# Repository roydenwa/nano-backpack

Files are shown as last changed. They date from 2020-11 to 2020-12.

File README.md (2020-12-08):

# Nano-backpack for NAO robot
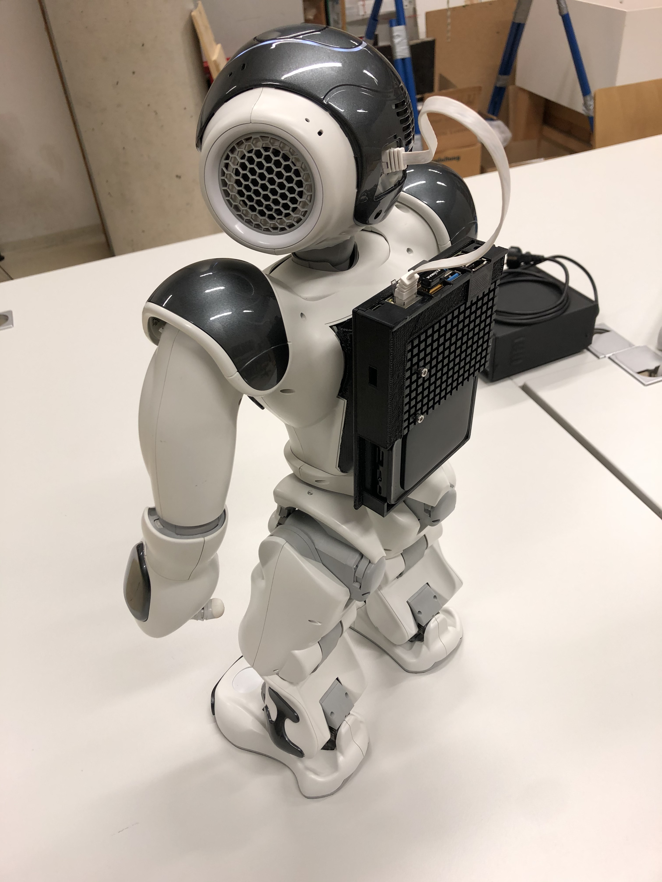
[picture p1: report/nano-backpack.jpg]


Nano-backpack is an open hardware add-on for the humanoid robot NAO. It adds
a Nvidia Jetson Nano development board to the robot and thereby enhances the computational capabilities of the system. The corresponding software architecture includes
a webapp to control the robot and allows an easy start into the development of further
applications.

This project was part of the Robotics Practical class (MScTI_ROBP) in summer term 2020 @ Heidelberg University.

## Setup:
<details><summary><b>Install and setup linux-wifi-hotspot on Jetson Nano</b></summary>

1. Install dependencies:

    ```sh
    sudo apt install -y libgtk-3-dev build-essential gcc g++ pkg-config make hostapd
    ```
2. Clone repo and build:

    ```sh
    git clone https://github.com/lakinduakash/linux-wifi-hotspot
    cd linux-wifi-hotspot

    # build binaries
    make

    # install
    sudo make install
    ```
3. Open application and create hotspot with `rndis0` preset
4. Run linux-wifi-hotspot on every startup:
    ```sh
    systemctl enable create_ap
    ```
</details>
<details><summary><b>Clone this repo and build Docker Image</b></summary>

1. Clone:
    ```sh
    git clone https://github.com/roydenwa/nano-backpack.git
    ```
2. Navigate to nano-backpack/src/app/ and build Docker image with:
    ```sh
    sudo docker build -t "nano-backpack" .
    ```
</details>
<details><summary><b>Install and run dnsmasq</b></summary>

1. Install dnsmasq:
    ```sh
    apt install dnsmasq
    ```
2. Run provided bash script to setup a subnet:
    ```sh
    sudo bash run_dnsmasq.sh
    ```
</details>
<details><summary><b>Run Docker image and connect to wifi-hotspot to see webapp with other devices</b></summary>

Start Docker image with interactive shell:
    `
    sudo docker run --rm -it -p 80:80 "nano-backpack"
    `
The webapp should now be visible at `192.168.12.1` if you are connected to the previously created wifi hotspot.
</details>
 
## License and credits
<br />This work is licensed under a <a rel="license" href="http://creativecommons.org/licenses/by/4.0/">Creative Commons Attribution 4.0 International License</a>.

This repo is built upon other open-source contributions:

* CAD models are partially based on [NAO-backpack](https://github.com/uchile-robotics/nao-backpack).
* The wifi hotspot is created with [linux-wifi-hotspot](https://github.com/lakinduakash/linux-wifi-hotspot).
* The unfinished concept for monocular depth estimation is based on [DenseDepth](https://github.com/ialhashim/DenseDepth).

## TODO:
- [ ] Docu
   - [x] Simplify Layout - Alex frist page - abstract and contents, header
    - [x] Abstract
    - [X] Introduction - Alex / Royden
    - [x] Related works Backpack - Alex
    - [X] Related works Monocular - Royden 
    - [ ] Related Works optional: linux-wifi-hotstpot ? - Royden
    - [ ] Instructions for Peter - Peter how to - Alex
        - [x] pw user on Nano
        - [x] pw wlan nano-bp
        - [x] ip ssh
        - [x] standard ip NAO robot
        - [x] Table compatible Naoqi-SDKs (Offical: Python: no(not suitable for ARM), Javascript: qimessaging yes, qi2: yes, C++: not tested, Third-party: ROS: deprecated,   NodeJs~yorki: yes)
        - [ ] Development Environment Nano:
        - [x] how to use docker and python on Nano with NAO
   - [X] Mechanical design - Royden
   - [X] Remote control NAO ~ UI5 - Royden / Alex
   - [X] Depth estimation - python-decorator - single-frame <-> video - Royden
   - [X] Conclusion: - Alex / Royden
      - [ ] benefit: easy start - dev env - UI for for testing
      - [ ] outlook: python base for depthestimation, JS base for more NAOqi-services
- [ ] App
   - [x] NAOs view - placeholder img of NAO - Alex
   - [X] ui5-datamodel ip, text params - Royden
   - [X] Import Error qimessaging - Royden
   - [ ] update readme, clean repo 
   - [X] Docker images - Royden

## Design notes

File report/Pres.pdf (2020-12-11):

## Robotics Practical

# Nano-backpack designed for humanoid NAO robot

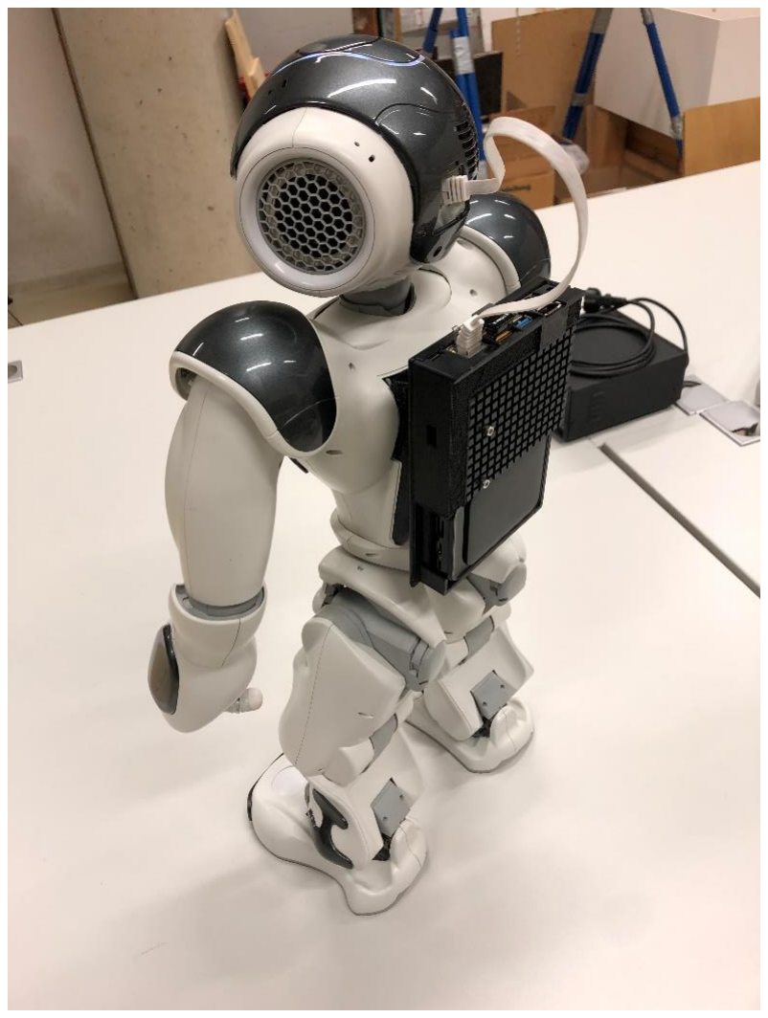
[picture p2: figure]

Slide 1 | 11.12.2020 | Barth, Wagner

## Mechanical design

- Battery cover integrated in printed backpack
- Access to all Nano connectors
- Improved heat sink

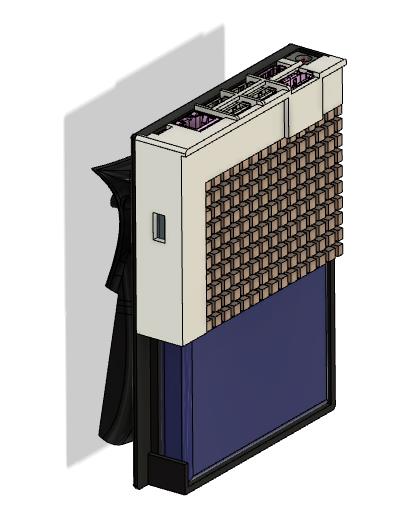
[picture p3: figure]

Slide 2 | 11.12.2020 | Nano-backpack designed for humanoid NAO robot | Barth, Wagner

## Nano

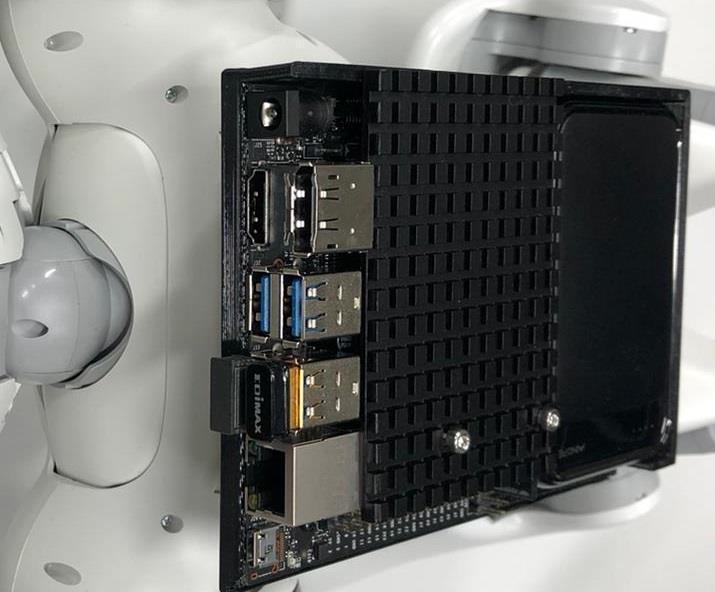
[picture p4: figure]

- Modern Linux environment
- Overcome NAO hardware
limitations
- Onboard power supply in the backpack
- GPU for greater possibilities in computer vision
Slide 3 | 11.12.2020 | Nano-backpack designed for humanoid NAO robot | Barth, Wagner

## System architecture

- Access Nano remotely
- Docker container runs web app

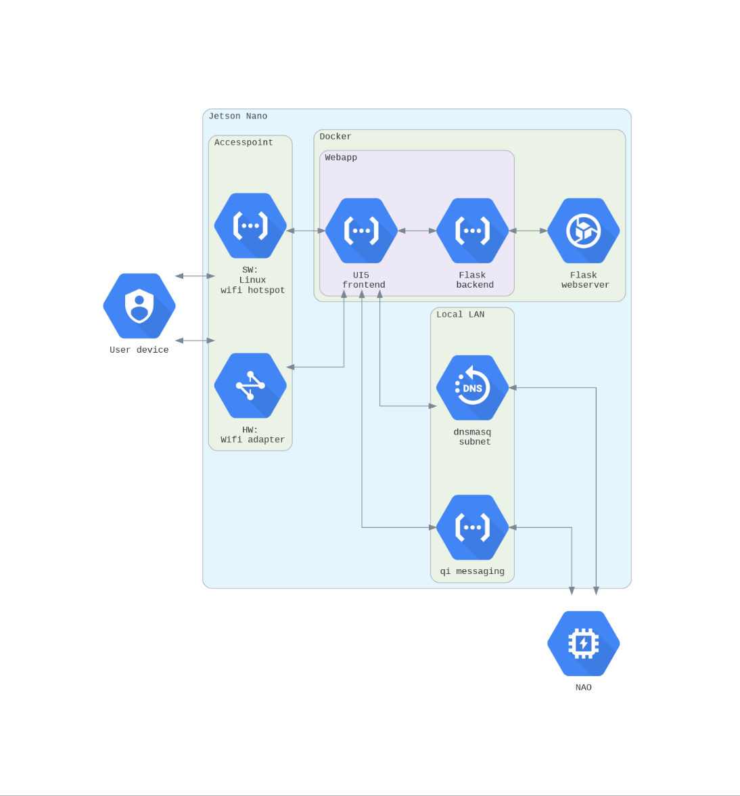
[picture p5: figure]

Slide 4 | 11.12.2020 | Nano-backpack designed for humanoid NAO robot | Barth, Wagner

## Docker

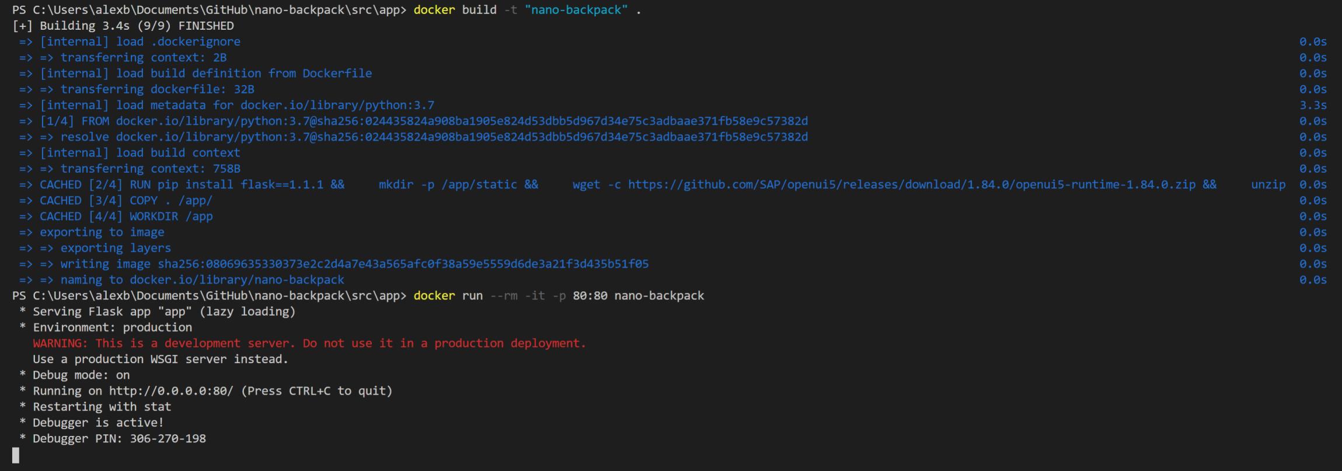
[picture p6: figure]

- Caching → build in few seconds, no internet access required
Slide 5 | 11.12.2020 | Nano-backpack designed for humanoid NAO robot | Barth, Wagner

## Webapp

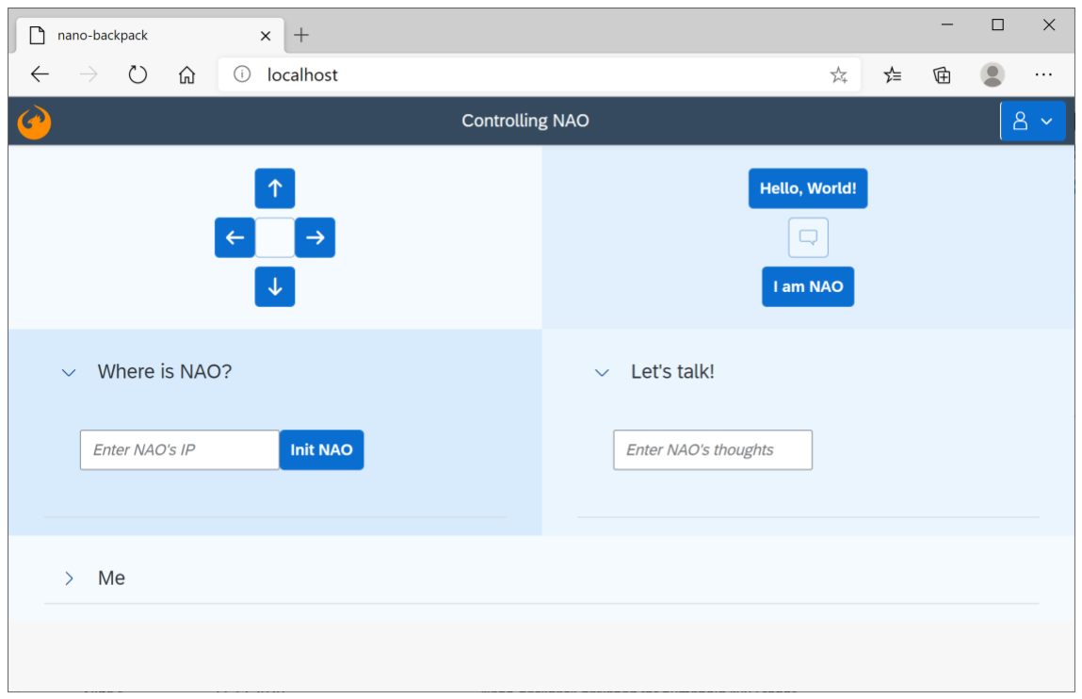
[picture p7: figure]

- UI5 front-end (JS)
- Flask back-end (Python)
- See video
Slide 6 | 11.12.2020 | Nano-backpack designed for humanoid NAO robot | Barth, Wagner

## Depth estimation in video stream

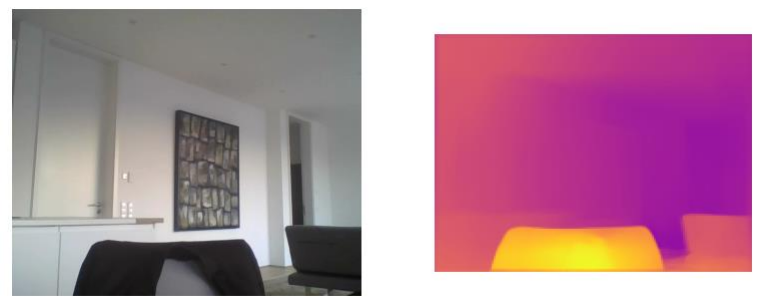
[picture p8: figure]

- Custom dataclass to handle video input
- Can later be combined with ALVideoDevice of the NAOqi-API
Slide 7 | 11.12.2020 | Nano-backpack designed for humanoid NAO robot | Barth, Wagner

## Benefits

1. Overcome previous hardware limitations
2. Easy start with step-by-step instructions
3. Reuse, modify, extend webapp and Docker image
4. State-of-the-art development environment
5. Ready-to-use depth estimation in video stream
Slide 8 | 11.12.2020 | Nano-backpack designed for humanoid NAO robot | Barth, Wagner

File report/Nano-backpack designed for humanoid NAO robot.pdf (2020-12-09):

# Nano-backpack designed for humanoid NAO robot

### Barth, Alexander

M.Sc. Student Computer Engineering

### Wagner, Royden

M.Sc. Student Computer Engineering

### Institute for Computer Engineering (ZITI)

University of Heidelberg

Abstract

Nano-backpack is an open hardware add-on for the humanoid robot NAO. It adds a Nvidia Jetson Nano development board to the robot and thereby enhances the computational capabilities of the system. The corresponding software architecture includes a webapp to control the robot and allows an easy start into the development of further applications. The source code and CAD models are available on GitHub: https://github.com/roydenwa/nano-backpack
An in-depth instruction manual is provided in an additional document.

## Contents

1 Introduction | 1
2 Related work | 1
3 Mechanical design | 2
4 Remote access and control NAO robot | 4
5 Depth estimation in video stream | 5
6 Conclusion and outlook | 8

## List of Figures

1 | Encoder-decoder architecture [2] | | 2
2 | Nano-backpack | | 2
3 | Bottom-cover of Nano-backpack and the standard battery-cover | | 3
4 | System overview | | 4
5 | Webapp | | 5
6 | Testing the depth estimator | | 7
7 | Depth-map for same scene with a person in background | | 7

## List of Source codes

1 | Custom dataclass - Video | | 6
2 | Custom decorator - tf inference | | 6

## 1 Introduction

This work is based on the humanoid and programmable robot NAO. NAO robots are developed by SoftBank Robotics and have become a standard in today’s education and research. The robot’s operating system is called NAOqi. SoftBank provides an API with several SDKs to interact with the NAO robot and develop applications via NAOqi.
The Nano-backpack is designed to add a Jetson Nano to the NAO to improve the robot’s computing power and to simplify accessing the robot. Jetson Nano is a single board computer developed by NVIDIA for embedded applications focused on machine learning and robotics. The Jetson Nano runs a Linux operating system and has a dedicated GPU, so GPU-versions of modern machine learning frameworks can be used for training and inference of machine learning models.
This work describes the mechanical design of the backpack, a webapp designed to control the NAO robot and provides the basis for a dedicated machine learning use-case for the system.

## 2 Related work

This section provides an overview of related work.

### 2.1 NAO Backpack

Softbank’s NAO may be today’s standard in education and research and provides advantages in comparison with other available humanoid platforms. Nevertheless it’s advantages come along with some drawbacks. The on-board processing power is one of the strongest limitations. Also some of the earlier software works with NAO are outdated. Therefore [1] introduce a open-hardware accesory for the NAO called NAO Backpack. With this backpack, the NAO is able to carry more powerful hardware and overcomes the previous limitations of testing with high wlan latency or long ethernet cables. The hardware upgrade creates a wide range

Nano-backpack designed for humanoid NAO robot | Summer term 2020

of possibilities in different research areas like computer vision because of the new hardwares’ GPUs. Henceforth more computational intensive algorithms can be used with the NAO.

### 2.2 Monocular Depth Estimation

Depth estimation is a computer vision task, where one or multiple input-images of a scene are converted into depth maps of that scene. The output of such a system is usually visualized with pseudo-colored depth images where different colors mark distances within the input-image. The standard approach for depth estimation is to use two stereo-images captured by a stereocamera and calculate distances within the scene using triangulation. A recent work showed that monocular depth estimation using machine learning can also lead to good results, although it uses only a single input-image of a scene. [2]
Alhashim and Wonka propose a fairly simple encoder-decoder architecture for this task:

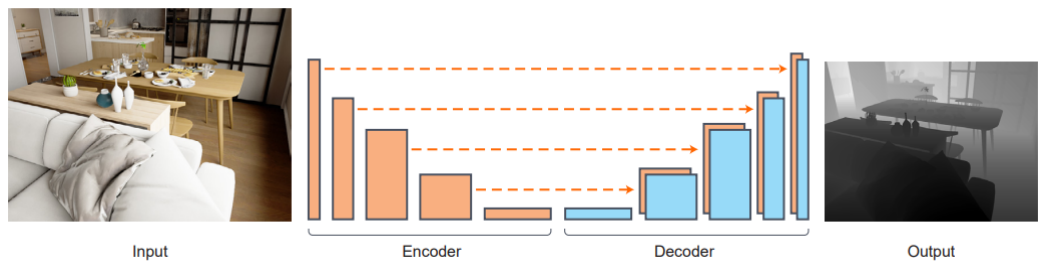
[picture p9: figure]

Figure 1: Encoder-decoder architecture [2]

The used encoder is a popular pretrained convolutional neural network, called DenseNet-
169. The filtered information is then fed into a decoder structure, consisting of multiple upsampling layers to reconstruct the pseudo-colored depth image. Additional skip-connections, which transfer information from the first layers directly to the last layers, further improve the performance.

## 3 Mechanical design

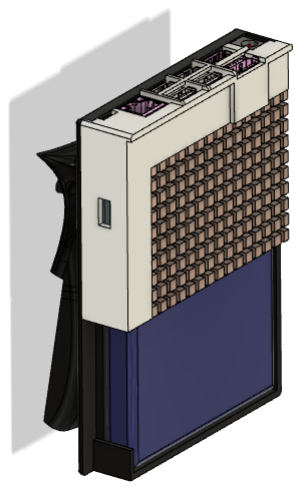
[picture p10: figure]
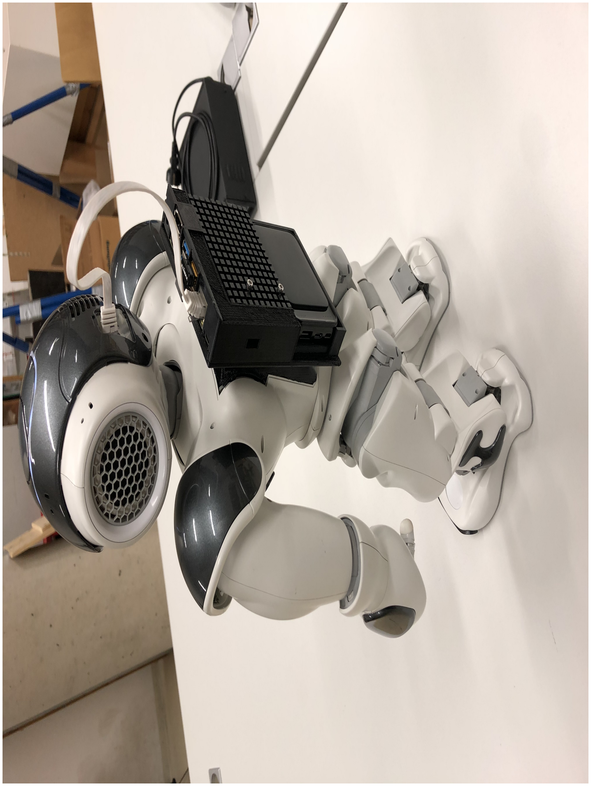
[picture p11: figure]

(a) CAD model | (b) Test unit mounted on NAO robot

Figure 2: Nano-backpack

The Nano-backpack is designed to carry a Nvidia Jetson Nano development-board and a LiPobattery to power it. It consists of three major parts, a bottom-cover, a top-cover and a flat copper heat sink, which completes the top-cover.
The bottom-cover is colored black in Figure 2 (a). In comparison to the ODROID development-board used by [1] the Jetson Nano has twice the amount of RAM and a much more powerful dedicated Nvidia GPU on board. This increase in computational capabilities comes at the cost of a bigger footprint and a higher power consumption. Therefore the backplate of [1], which replaces the standard battery-cover of the NAO robot, is reused in the bottom-cover, but the rest of it is redesigned to fit the bigger components.

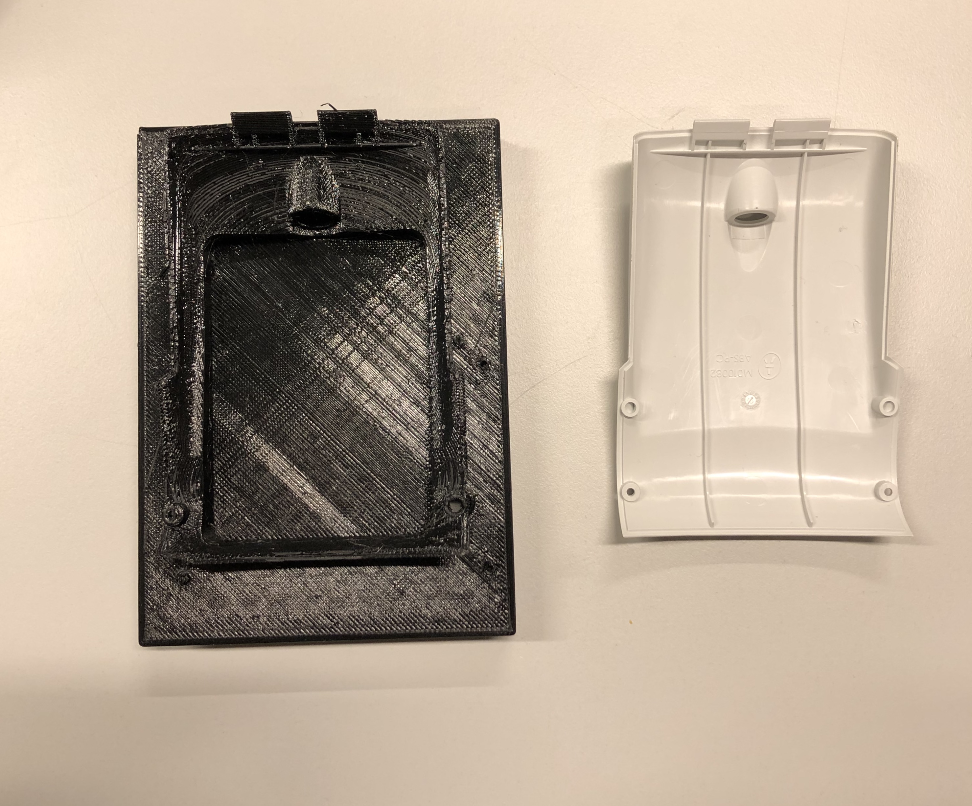
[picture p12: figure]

Figure 3: Bottom-cover of Nano-backpack and the standard battery-cover

In the upper area of the bottom-cover there is space for the Jetson Nano and holes for its attachment with screws. In the lower area of the bottom-cover there is space for a LiPo battery manufactured by AINOPE. This battery model has a capacity of 5000 mA h and is able to power the Jetson Nano operating in 5W or in 10W mode. [Appendix B] The battery is mounted inside the bottom-cover using double sided tape.
The top-cover is colored white in Figure 3 (a) and it is designed to allow access to the various connectors of the Jetson Nano. For easy access, all those connectors are facing upwards, when the backpack is mounted on a NAO robot. In Detail the Nano-backpack is intended to be used with a Ethernet cable connecting the Jetson Nano and the NAO robot and a Wifi dongle for accessing the Jetson Nano via Secure Shell, ssh. The top-cover also has a cut-out on the side in which a switch can be mounted to switch the Jetson Nano on and off.
The top- and bottom-cover in the test unit of the Nano-backpack are 3D-printed with PETG at Heideleberg University.
The top view of the Nano-backpack is completed by a newly designed heat sink for the Jetson Nano. This custom heat sink is made out of pure copper and is significantly lower and wider than the standard heat sink that comes with the Jetson Nano. Overall, the new heatsink is used as cover and is also better suited for use as a passive heat sink due to its material and design.
In Detail, the standard heat sink is made out of AL6061-T6 aluminium, has a volume of 1.64 × 10⁴ mm³

and a surface area of 1.77 × 10⁴ mm²
, the new designed heat sink has a volume of 1.4 × 10⁴ mm³

and a surface area of 1.94 × 10⁴ mm² . Consequently, the surface area is 9.6% larger, which improves heat conduction to the surrounding air. In addition, the new heat sink is better suited to conduct heat away from the heat source due to its larger footprint and the lower thermal resistance in copper in comparison to aluminium. [3] Furthermore, the new heat sink for the test unit, like the standard one, is painted black to protect it from corrosion. The newly designed heat sink is mounted on the Jetson Nano with six screws, heat conducting tape and a special thermal transfer plate designed by Connect Tech Inc. The thermal transfer plate is designed to fit the surface of the Jetson Nano Chip. [Appendix C]

## 4 Remote access and control NAO robot

This section describes a webapp and the surrounding architecture on the Nano-backpack.

### 4.1 Architecture

The next figure shows the interaction of hardware and software components that enable the development of complex applications for the NAO robot with the Nano-backpack:

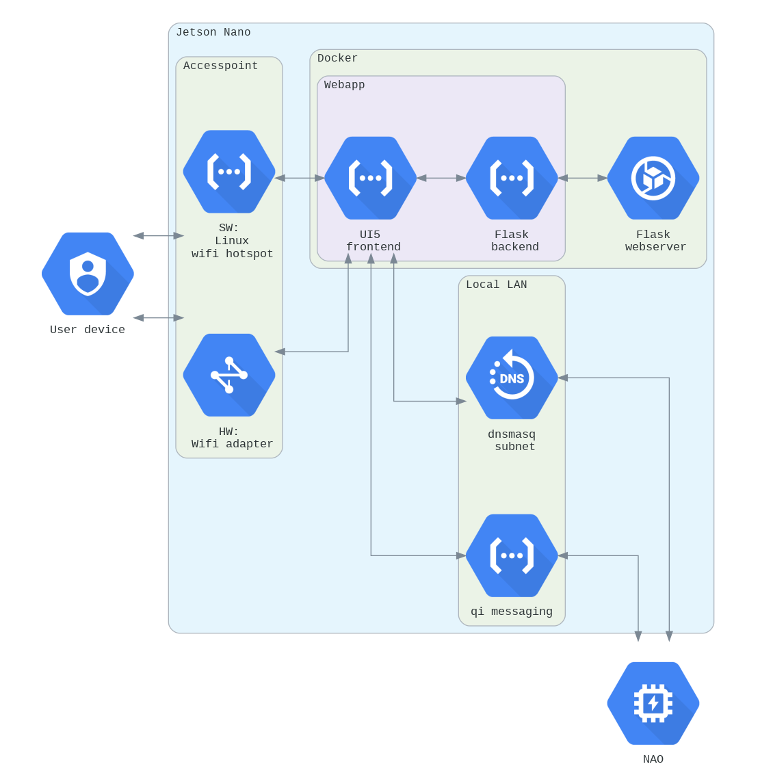
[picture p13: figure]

Figure 4: System overview

With a N150 Wifi dongle the Jetson Nano is used as wifi hotspot. Software-wise this hotspot is created with every boot-process using the open source library linux-wifi-hotspot by Lakindu Akash. [4] This creates a local wifi network to which you can connect with a laptop or cell phone, for example. If you are connected to this wifi network, you can access the Jetson Nano via Secure Shell, ssh, view or modify files and even execute programs. If you are connected you can also see webapps running on the Jetson Nano if you navigate to the right URL in a browser on your own device. Thereby a ssh-connection can be used to start or modify the provided webapp or to develop and run own webapps on the Nano.
In Detail, the provided web app runs inside a Docker container on the Jetson Nano. Docker is a software tool which virtualizes operating systems and is very useful and common in web development. It can be used to encapsulate a webapp, the needed software dependencies and a suitable ”virtual” operating system. [5]
The Ethernet connector of the Jetson Nano is used to connect it to the NAO robot via Ethernet cable. Software-wise this connection is managed with the open-source library dnsmasq and a custom bash-script. The custom script generates local sub-network for a given IP-address-range and provides a Domain Name System, DNS, for it. Thereby webapps running on the Jetson Nano can exchange messages and data with the NAO robot.

### 4.2 Webapp

The provided webapp has a back-end written in Python with the web-framework Flask and a front-end written in JavaScript with the framework OpenUI5. Flask is an open source web-framework written by Armin Ronacher that can be used to template HTML or to render pre-build templates provided by another framework. OpenUI5 is an open source framework provided by SAP that can be used to create responsive user interfaces for different devices. For the communication of the webapp with the NAO robot the qi2 SDK for the NAOqi API is used. This SDK is the newest one written in JavaScript.

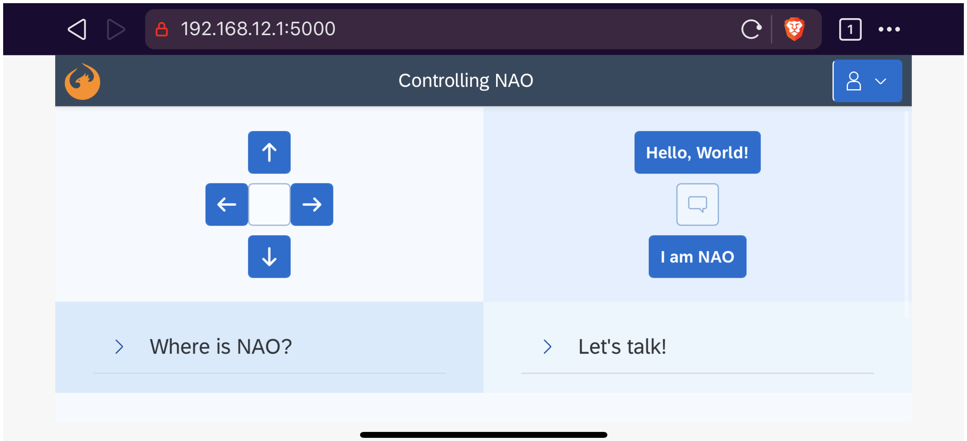
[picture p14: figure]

Figure 5: Webapp

The control pad on the left side can be used to control the robot via the ALMotion service. The buttons on the right can be used to let the robot say predefined quotes via the ALTextToSpeech service. The two tiles below are placeholders for further functions.

## 5 Depth estimation in video stream

Alhashim and Wonka provide functions to use their pretrained depth estimator on single images.[2] Following a method is described, how video data can be analyzed with the pretrained depth estimator.
This method is based on the open-source computer vision library OpenCV. OpenCV was originally written in C/C++ but in this method OpenCV-Python is used, which is a wrapper that makes the functionality of OpenCV available in Python.

A custom Python-dataclass is used to handle video-input:

1 | @dataclass
2 | class Video:
3 | '''
4 | Dataclass to manage video input with cv2
5 | src = 0 -> webcam
6 | '''
7 | src: int
8 | width: float
9 | height: float
10 | cap: object = field(init=False)

11
12 | def __post_init__(self):
13 | self.cap = cv2.VideoCapture(self.src)
14 | self.cap.set(3, self.width)
15 | self.cap.set(4, self.height)

16
17 | @tf_inference
18 | def get_frame(self):
19 | ret, frame = self.cap.read()
20 | if ret:
21 | return frame

Listing 1: Custom dataclass - Video

This dataclass wraps the VideoCapture class of OpenCV and adds a custom decorator for the machine learning inference (line 17). Alhashim and Wonka use the machine learning library TensorFlow to implement their depth estimator, following all TensorFlow related variables and functions contain the abbreviation ”tf”. The decorator @tf_inference wraps the get_frame() function and thereby applies the machine learning inference to every single frame of an input-video:

1 | def tf_inference(func, max_depth=1000, min_depth=10):
2 | ''' tf decorater func for Video class '''
3 | def func_wrapper(*args, **kwargs):
4 | frame = func(*args, **kwargs)

5
6 | if "model" in globals():
7 | # convert frame for tf and depth-model
8 | frame_tf = cv2.cvtColor(frame, cv2.COLOR_BGR2RGB)
9 | frame_tf = np.clip(np.asarray(frame_tf, dtype=float) / 255, 0, 1)
10 | frame_tf = frame_tf[np.newaxis, ...]

11
12 | # get predictions and convert back to img
13 | predictions = model.predict(frame_tf, batch_size=2)
14 | depth_frame_raw = predictions[0, :, :, :]
15 | depth_frame_raw *= 255.0 / depth_frame_raw.max()
16 | depth_frame_raw = np.array(depth_frame_raw, dtype=np.uint8)

17
18 | # pseudo-colorize:
19 | depth_frame_color = cv2.applyColorMap(depth_frame_raw, cv2.COLORMAP_PLASMA)

20
21 | return frame, depth_frame_color
22 | else:
23 | return frame
24 | return func_wrapper

Listing 2: Custom decorator - tf inference

The decorator also checks if a machine learning model is provided as global variable and returns just the frame if no model is provided. The custom dataclass Video can therefore be used with and without machine learning to manage video-input. Finally the pseudo-colored depth-frame is created by applying the applyColorMap() function of OpenCV to the predicted depth-frame.
Alhashim and Wonka provide two pretrained versions of their depth estimator, one trained on the KITTI dataset and one trained on the NYU Depth V2 dataset. The KITTI dataset is intended for autonomous driving and therefore features images of street scenes, the NYU Depth V2 features images of indoor scenes. NAO robots are mostly used indoors, so the on NYU Depth V2 dataset trained model fits this use-case.
The next figure shows how this pretrained model performs on unseen data. For pseudocoloring the OpenCV color-map COLORMAP PLASMA is used, where distant objects are marked violet and close objects yellow:

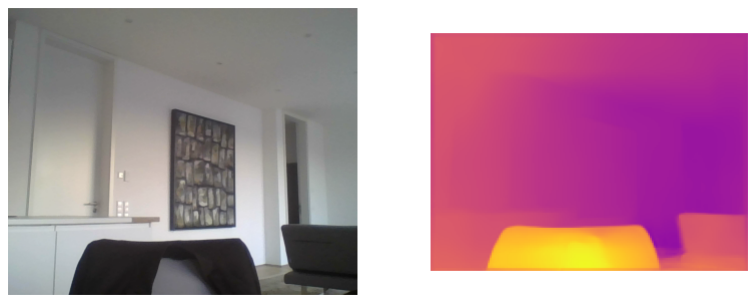
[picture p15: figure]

Figure 6: Testing the depth estimator

It detects correctly that the chair and the couch are relatively close to the camera. It also correctly detects that the walls are clearly behind it and the point furthest away is in the middle of the right side. All in all, the level of detail is rather low.
It is interesting that especially humans are well recognized, in the following picture is the same scene with a person in the background:

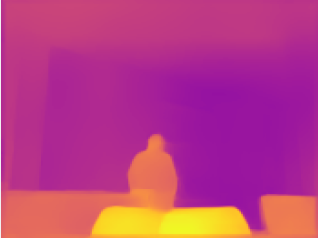
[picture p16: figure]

Figure 7: Depth-map for same scene with a person in background

The NYU dataset contains RGB-images with a width of 640 pixels and a height of 480 pixels. The performance tests show that the pre-trained model also gives good results when the input images have a width of 352 pixels and a height of 288 pixels. Especially with video input, this reduces the computational complexity and shortens the time needed for inference.

## 6 Conclusion and outlook

Nano-backpack can be seen as an extension of the NAO robot, which increases the computing power of the system and at the same time enables an easy start into the development of further applications. Prospective users can use the provided webapp and should be able to let NAO walk and speak within minutes. This webapp and the corresponding Docker image can also be easily reused, modified or extended and thus be adapted to future requirements. For example the provided custom Python dataclass for depth estimation in videos could be combined with the ALVideoDevice service of the NAOqi-API. The entire architecture of the Nano-backpack enables the development in a modern Linux environment in which NAO-specific and many common software libraries are already available.

## References

[1] M. Mattamala et al. “The NAO Backpack: An Open-hardware Add-on for Fast Software Development with the NAO Robot,” arXiv preprint, 2017.
[2] I. Alhashim and P. Wonka. “High Quality Monocular Depth Estimation via Transfer Learning,” arXiv preprint, 2019.
[3] National Bureau of Standards U.S. Department of Commerce Boulder “THERMAL CON-DUCTIVITY OF ALUMINUM, COPPER, IRON, AND TUNGSTEN FOR TEMPERA-TURES FROM 1 K TO THE MELTING POINT”, Colorado, June 1984.
[4] Lakindu Akash, ”linux-wifi-hotspot”, 2019, https://github.com/lakinduakash/linux-wifihotspot
[5] Sahiti Kappagantula, ”Docker Explained – An Introductory Guide To Docker”, 2020, https://www.edureka.co/blog/docker-explained/
[6] Archlinux, ”Dnsmasq”, November 2020, https://wiki.archlinux.org/index.php/Dnsmasq

## Appendix A:

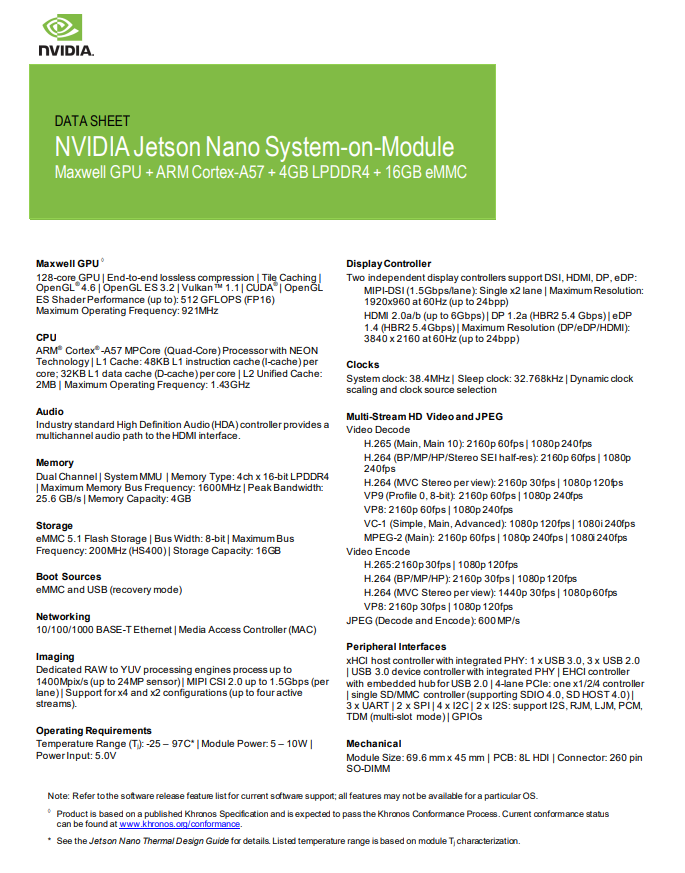
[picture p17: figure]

## Appendix B:

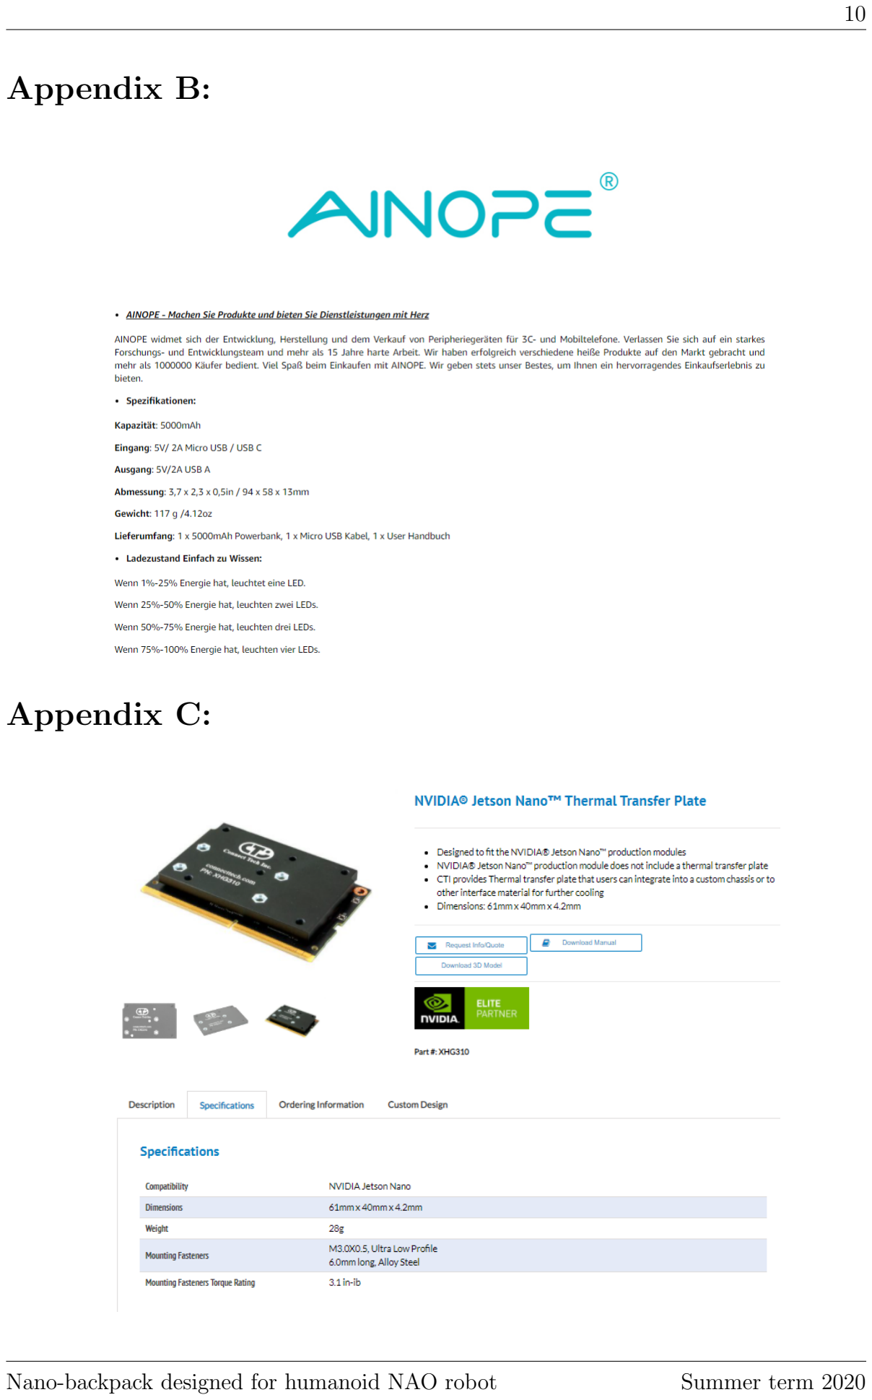
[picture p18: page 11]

## Appendix C:

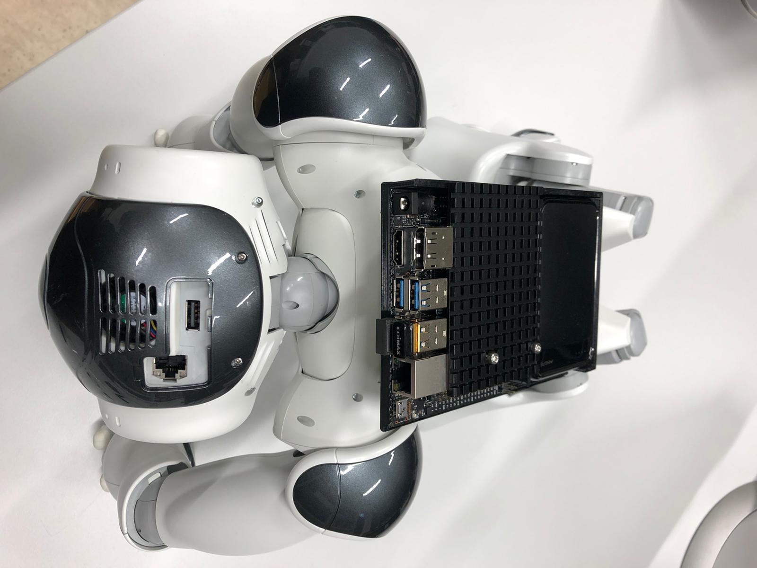
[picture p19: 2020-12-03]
report/nano.jpeg

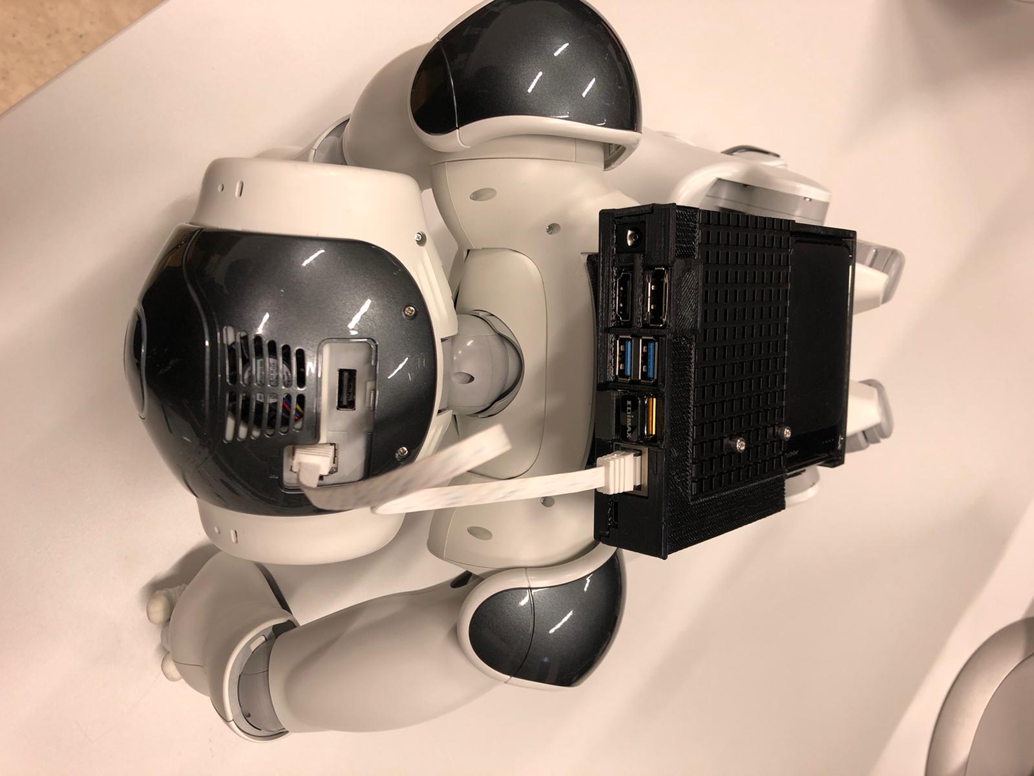
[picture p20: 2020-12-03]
report/cable.jpeg

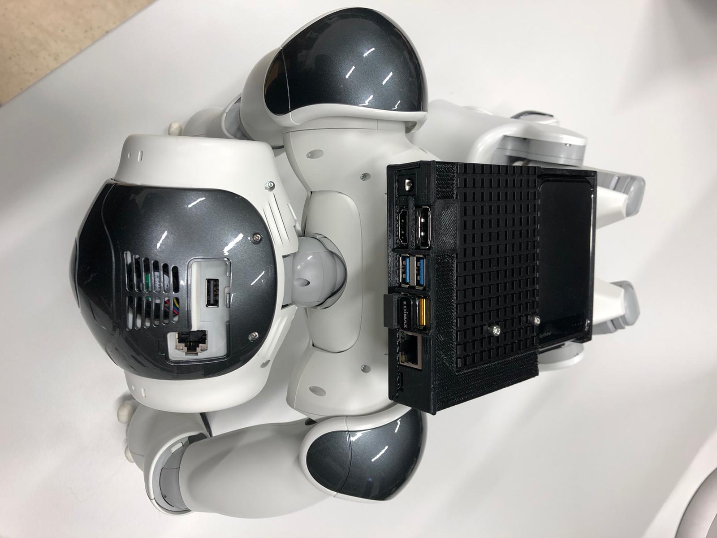
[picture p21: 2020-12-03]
report/upper.jpeg

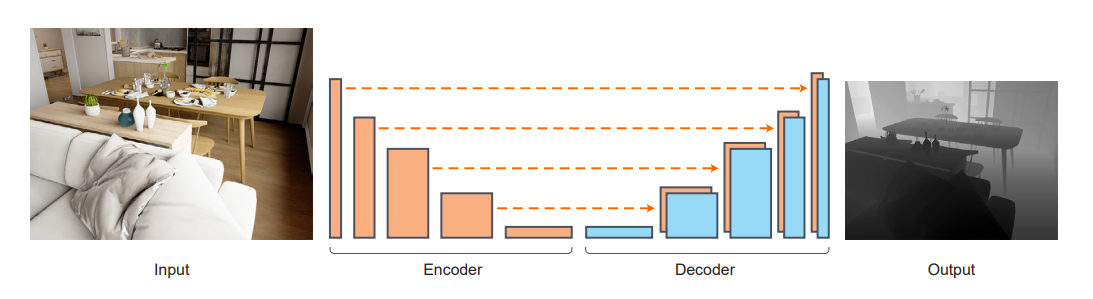
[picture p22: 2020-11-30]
report/encoder-decoder-architecture.PNG

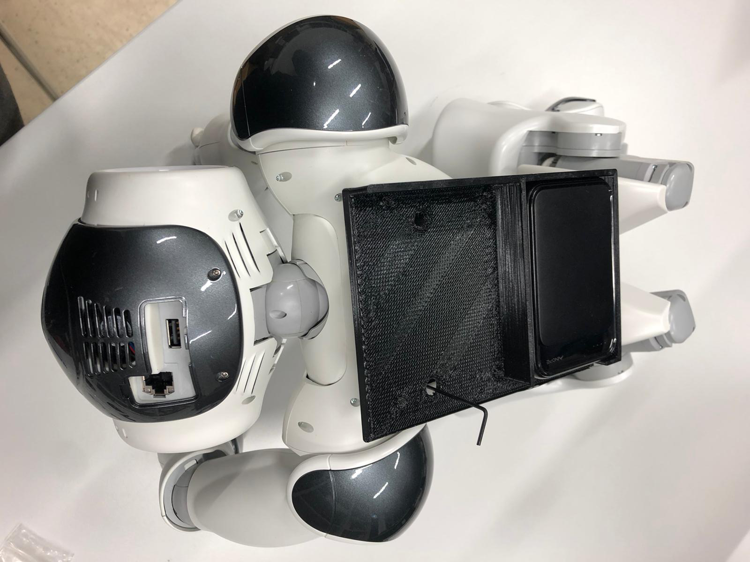
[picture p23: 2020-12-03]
report/lower.jpeg

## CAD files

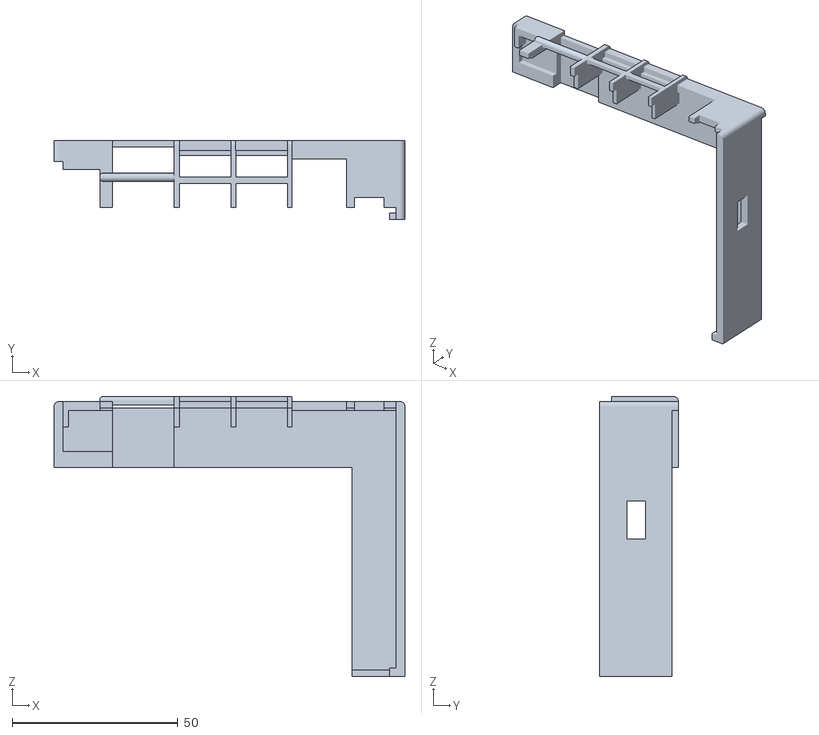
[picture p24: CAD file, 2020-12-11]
stl-files/nano-backpack-top-cover.stl
105.9 x 23.9 x 84.5

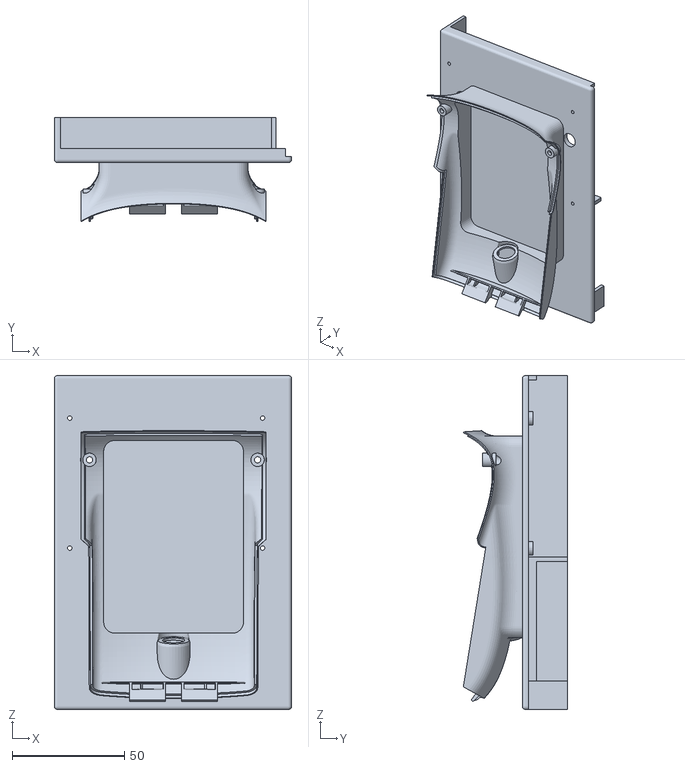
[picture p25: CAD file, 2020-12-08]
stl-files/nano-backpack-bottom-cover.stl
105.9 x 46.5 x 149.0

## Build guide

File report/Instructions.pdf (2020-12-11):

# Nano-backpack instructions

### Barth, Alexander

M.Sc. Student Computer Engineering

### Wagner, Royden

M.Sc. Student Computer Engineering

### Institute for Computer Engineering (ZITI)

University of Heidelberg

## Contents

1 Step-by-step | 1
1.1 Hardware | | 1
1.2 Software | | 2
2 Development environment | 2
3 NAOqi-SDKs | 3
4 Data | | 3

## List of Figures

1 | Mounting steps | | 1

## List of Source codes

1 | Start development server | | 2

## List of Tables

1 | NAOqi-SDKs | | 3
2 | Data and commands | | 4

## 1 Step-by-step

This section provides step-by-step instruction for using the Nano-backpack on NAO starting with the mounting. To use the project on another Jetson Nano, follow the structure described in https://github.com/roydenwa/nano-backpack.

### 1.1 Hardware

To mount the Nano-backpack onto the NAO robot follow the steps shown in Fig. 1

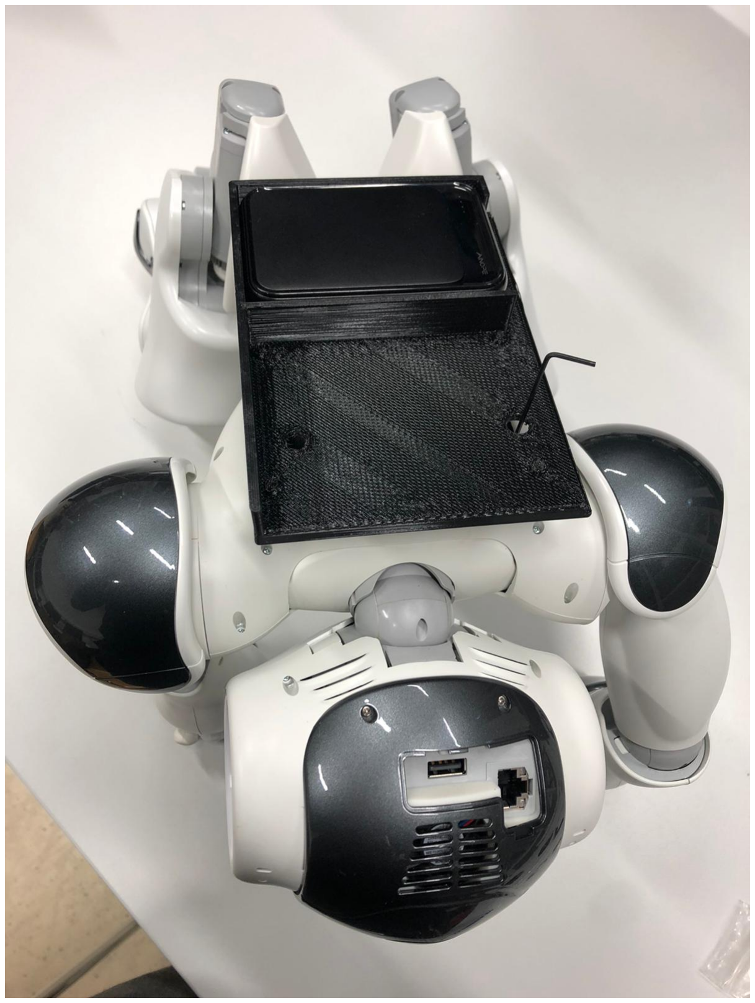
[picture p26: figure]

(i) Lower backpack part | (ii) Nano and powerbank


(iii) Upper backpack part | (iv) Ethernet cable

Figure 1: Mounting steps

1. Remove the battery cover and instead fix the printed backpack with screws on the back of the robot.
2. Insert the Nano and the powerbank into the backpack.
3. Close the Nano-backpack with the upper backpack part.
4. Connect NAO with it’s Nano-backpack by using the flat ethernet cable.*

* This step completes the installation of the hardware, but may be done later, as described in the step-by-step part for software.

Nano-backpack instructions | Summer term 2020

### 1.2 Software

This subsection focuses on the software but requires several steps with hardware included.

1. Connect the Nano to it’s power supply.
Note: Do not connect the ethernet cable yet.
2. Start NAO by pressing it’s chest button.
Note: Continue with the following steps so that NAO’s boot process is finished when required.
3. Wait until the wlan adapter lights up blue.
The boot process is finished and Nano’s wlan is ready for your connection.
4. Connect to Nano’s wlan.
Name: nano-bp
Password: 12345678
5. Connect to Nano via SSH.
Command: ssh nao-bp@192.168.12.1
User password: nao9
6. Run the dnsmasq batch script to setup the network sharing with NAO correctly. Command: sudo bash run dnsmasq.sh
7. Connect NAO with it’s Nano-backpack using the ethernet cable.
Note: NAO’s default IP is 192.168.2.37.
8. Run the dockerimage. For more information on using Docker see Section 2. Command: docker run –rm -it -p 80:80 nano-backpack

## 2 Development environment

On the Nano are docker and python available and contain the app to remote control NAO via web application. The dockerfile contains the commands necessary while building the dockerimage. To build and start the dockerimage navigate to the working directory of the app and execute the following commands shown in Listing 1. Docker runs an application coming with an user interface which can be used for testing.

1 | # build dockerimage
2 | docker build -t "nano-backpack" .
3 | # start dockerimage
4 | docker run --rm -it -p 80:80 nano-backpack

5
6 | # start development server without docker
7 | python app.py

Listing 1: Start development server

The app should now run at 192.168.12.1. After changes to the UI5-frontend a manual restart of the app is required. Disabling browser caching is not working on chrome, so firefox or edge should be used instead for development.
The provided code base of the webapp and Docker can easily be reused, modified or extended and thus be adapted to future requirements. In this way more NAOqi services can be added. An example is the ALVideoDevice, which can be combined with the ready-to-use depth estimation for video stream input.
For accessing the internet with Nano a lan connection is recommended. There may be difficulties with the Nano’s wlan connection when it’s network is set up.

## 3 NAOqi-SDKs

This table shows an overview of different Naoqi SDKs. The limitation due to ARM results from using Jetson Nano. The rating is based on the created system architecture or one of it’s preliminary stages.

Table 1: NAOqi-SDKs

Release | Language | Operates | Notes
Official | C++ | | Not tested
| JS Qi2 | ✓
| JS QiMessaging | ✓
| Python | ✕ | Not suitable for ARM
Third-party | JS Node-naoqi | ✓ | See yorkie on GitHub
| ROS | ✕ | Deprecated, also see Python

The testing of further packages is left to future work.

## 4 Data

This section summarizes useful data which is used above. The following appendix also contains the data sheets for the Nano and its battery.
Model data for printing the backpack and it’s cover, as well as all codes used can be found at https://github.com/roydenwa/nano-backpack.

Table 2: Data and commands

App | Location | 192.168.12.1
Docker | Build command | docker build -t ”nano-backpack” .
| Run command | docker run –rm -it -p 80:80 nano-backpack
NAO | Default ip | 192.168.2.37
SSH | Command | ssh nao-bp@192.168.12.1
User | Name | nao-bp
| Password | nao9
Wlan | Name | nano-bp
| Password | 12345678

## Appendix A:


## Appendix B:

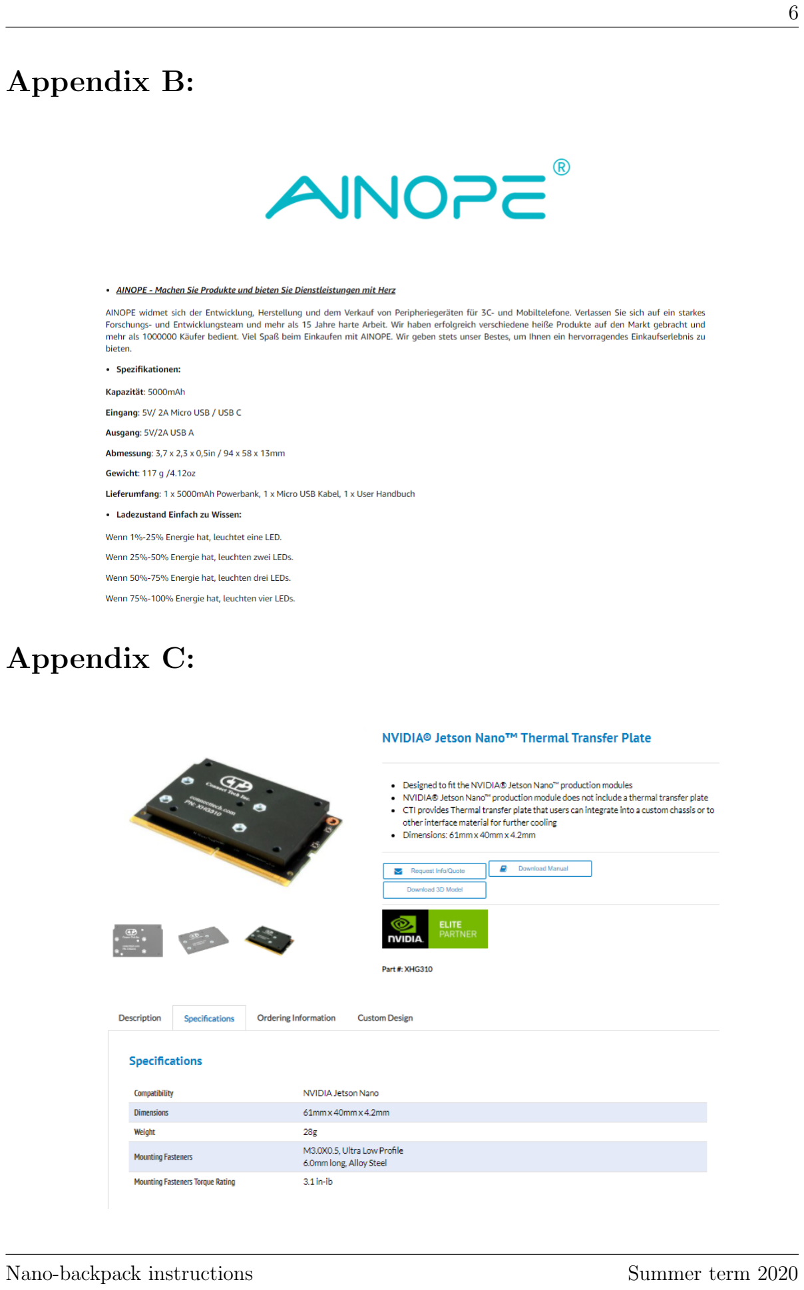
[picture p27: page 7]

## Appendix C:

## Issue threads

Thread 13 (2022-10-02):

Editable CAD file?

junnikokuki, 2022-10-02:
Hi,
I want to make a backpack for my NAO, and due to the out of stock of the the power bank, I need to modify the 3d print part to fit my power bank. The stl file is not modifiable, can you provide an editable format of the 3d print part? Thank you.

roydenwa, 2022-10-10:
Hi, happy to hear that. Unfortunately, I don't have the CAD files on my PC anymore. But, they are based on the nao-backpack model and they provide step files at: https://github.com/uchile-robotics/nao-backpack/tree/master/backpack_cad
So, maybe you can recreate it with that.

junnikokuki, 2022-10-12:
Okey, Thanks.

Closed 2022-10-12.

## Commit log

2020-07-26 added BGR2RGB and normalized frame to (0, 1)
2020-10-23 added boilerpalte for UI5 webapp with flask backend
    [App.view.xml]
2020-10-29 switched to node-naoqi
2020-10-29 changed base image to support arm
2020-11-12 started controller layout
    [App.view.xml]
2020-11-19 added headerbar
    [App.view.xml]
2020-11-19 press funcs
    [App.view.xml]
2020-11-24 switched to local openui5-runtime for offline usage
2020-11-26 integrate qi-messaging into ui5 frontend
    [App.view.xml]
2020-11-28 added btn to init qi-session
    [App.view.xml]
2020-12-01 incl image, but not found
    [App.view.xml]
2020-12-03 Update App.view.xml
    still no img shown
    [App.view.xml]
2020-12-03 removed unused page and funcs
    [App.view.xml]
2020-12-03 set vals for walking and speaking
    [App.view.xml]
2020-12-03 removed comments
    [App.view.xml]
2020-12-03 switched to default port 80
2020-12-03 fixed path2img
    [App.view.xml]
2020-12-03 mounting imgs
2020-12-04 renamed folder
    [App.view.xml]
2020-12-08 added stl-file of bottom-cover
    [nano-backpack-bottom-cover.stl]
2020-12-11 added stl-file for top-cover
    [nano-backpack-top.stl]
2020-12-11 added stl-file of top-cover
    [nano-backpack-top-cover.stl]
